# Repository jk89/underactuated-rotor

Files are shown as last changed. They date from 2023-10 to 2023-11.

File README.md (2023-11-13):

# Underactuatuated Rotor

Project for controlling a bldc motor with a ps4 controller, fulfilling the underactuated rotor mechanism.

# How to run

0. Load underactuated-arduino-uno.io onto device.
1. Start sending commands from ps4 controller to remote: python3 remoteCommand.py
2. Start graphing: bokeh serve --show graphServer.py 
3. Starting the Arduino Uno command server python3 commandServer.py

# [Circuit](https://github.com/kaepek/sbldc-smt)

# Models

## Minimal v1

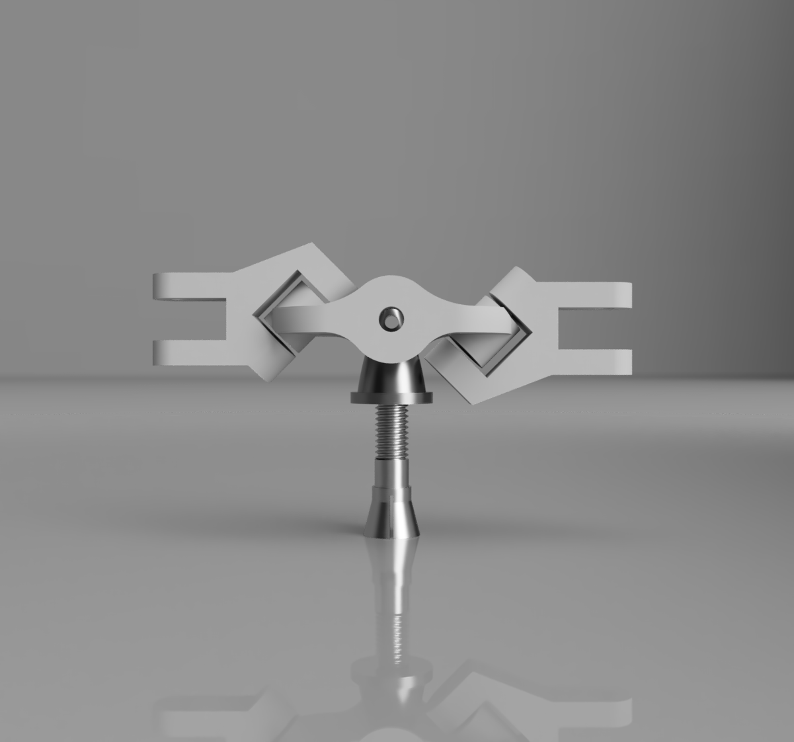
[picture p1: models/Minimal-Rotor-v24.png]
V1 model image

- [V1 model link](./models/Minimal-Rotor-v24.f3z)

## Hex Design v2

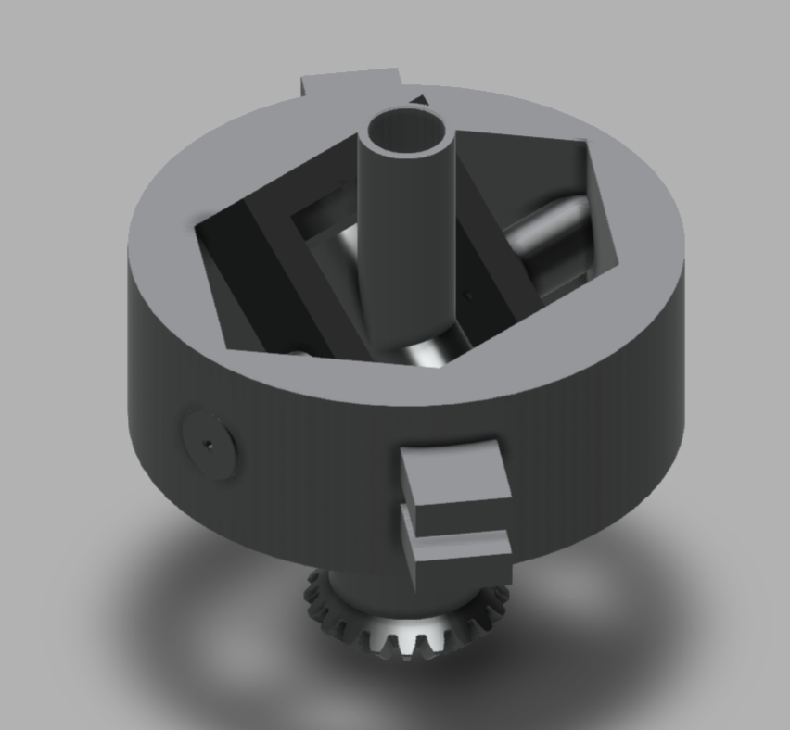
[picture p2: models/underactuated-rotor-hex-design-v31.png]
V2 model image

- [V2 model link](./models/underactuated-rotor-hex-design-v31.f3d)

## Hex Design v3

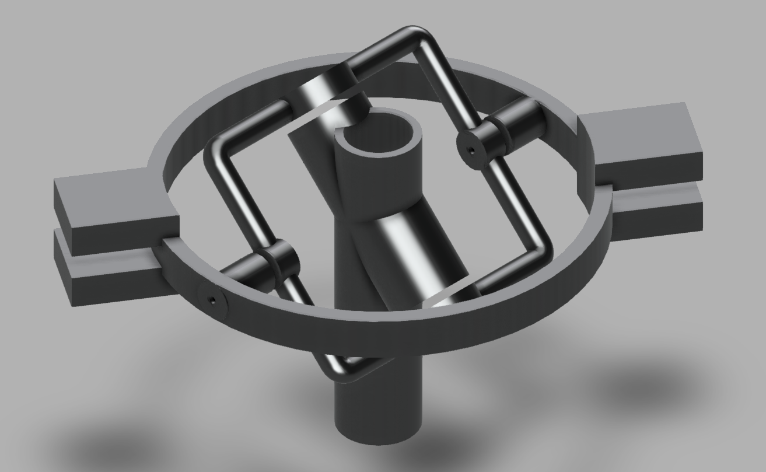
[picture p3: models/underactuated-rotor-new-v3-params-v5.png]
V3 model image

- [V3 model link](./models/underactuated-rotor-new-v3-params-v5.f3d)

# Draft notes on models:

[Notes](./resources/notes.pdf)

# Credits

- [Modlab UPenn](https://www.modlabupenn.org/underactuated-rotor/)
- [Paper](https://www.modlabupenn.org/wp-content/uploads/paulos_an_underactuated_propeller_IROS_2013.pdf)
- Steve Kelsey (Minimal rotor design)
- [Circuit reference](https://simple-circuit.com/arduino-sensorless-bldc-motor-controller-esc/)

# Disclaimer

This is an experimental project. I have destroyed a great deal of hardware (motors, transistors, ICs) and almost caused a fire once. Please be careful when using this code. ABSOLUTELY NO WARRANTY. If you do not agree to this then please do not download this software as this would violate the license which this code was distributed with, see [./LICENSE](./LICENSE) for details.

Moreover this project lacks sensible precautions with the ESC to halt the motor when its in a faulty state (aka something is in the way of the motor spinning). Due to its prototype nature represents a threat to you, if suitable personal protective gear and precautions are not made. I recommend building some sort of protective enclosure before one could safely experiment with the setup.

# License

Work is licensed under a
Creative Commons Attribution-NonCommercial 4.0 International License.

You should have received a copy of the license along with this
work. If not, see <https://creativecommons.org/licenses/by-nc/4.0/> or [plain text license](https://creativecommons.org/licenses/by-nc/4.0/legalcode.txt)

Released under fair use for educational purposes, strictly not for commercial use.

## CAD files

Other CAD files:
models/Minimal-Rotor-v24.f3z
models/underactuated-rotor-hex-design-v31.f3d
models/underactuated-rotor-new-v3-params-v5.f3d

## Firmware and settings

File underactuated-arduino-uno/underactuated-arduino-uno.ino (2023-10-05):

#define PWM_MAX_DUTY 240
#define PWM_MIN_DUTY 20
#define PWM_START_DUTY 20
#define n_BLDC_cycles 7
#define PI 3.1415926535897932384626433832795
#define MAX_PITCHROLL 32767

const float full_cycle = 2 * PI;
const byte motor_step_mod = n_BLDC_cycles * 6;
const float step_angle = full_cycle / motor_step_mod;

boolean modulated_thrust_mode = false;
const int EN1 = 2;
int x = 0;
byte bldc_step = 0, motor_speed;
int motor_step = 0;
int i = 0;

float sin_comp[motor_step_mod];
float cos_comp[motor_step_mod];
void build_angle_tables()
{
  for (byte z = 0; z < motor_step_mod; z++)
  {
    const float angle = step_angle * (float)z;
    sin_comp[z] = sin(angle);
    cos_comp[z] = cos(angle);
  }
}

float n_pitch = 0.0;
float n_roll = 0.0;
byte n_duty_target = PWM_START_DUTY;
byte duty_dynamic = n_duty_target;

/*
  port B digital pin x,x,13,12,11,10,9,8
  DDRB - The Port B Data Direction Register - read/write
  PORTB - The Port B Data Register - read/write
  PINB - The Port B Input Pins Register - read only
*/

/*
  portD digital pins 7,6,5,4,3,2,1,0
  DDRD - The Port D Data Direction Register - read/write
  PORTD - The Port D Data Register - read/write
  PIND - The Port D Input Pins Register - read only
*/

boolean first = true;

const int size_of_float = sizeof(float);
struct DATA_W
{
  float roll;
  float pitch;
} axesStuct;

void read_host_profile()
{
  char thrust = Serial.read();
  Serial.readBytes((char *)&axesStuct.roll, size_of_float);
  Serial.readBytes((char *)&axesStuct.pitch, size_of_float);
  n_pitch = axesStuct.pitch;
  n_roll = axesStuct.roll;
  n_duty_target = thrust;
}

void setup()
{

  build_angle_tables();
  modulated_thrust_mode = false;
  pinMode(EN1, OUTPUT);
  digitalWrite(EN1, HIGH);
  Serial.begin(9600);

  // portD digital pins 7,6,5,4,3,2,1,0
  // port B digital pin x,x,13,12,11,10,9,8

  DDRD |= B00111000; // 0x38;           // Configure pins 3, 4 and 5 as outputs
  PORTD = B00000000; // write all zeros to enable phase pins 3, 4, 5

  DDRB |= B00001110; // 0x0E;           // Configure pins 9, 10 and 11 as outputs
  PORTB = B00110001; // write zeros to 9, 10 , 11

  // Timer1 module setting: set clock source to clkI/O / 1 (no prescaling)
  TCCR1A = 0;
  TCCR1B = 0x01;
  // Timer2 module setting: set clock source to clkI/O / 1 (no prescaling)
  TCCR2A = 0;
  TCCR2B = 0x01;

  n_duty_target = PWM_START_DUTY;
  SET_PWM_DUTY(PWM_START_DUTY); // Setup starting PWM with duty cycle = PWM_START_DUTY

  // Analog comparator setting
  ACSR = 0x10; // Disable and clear (flag bit) analog comparator interrupt

  x = 0;
}

void loop()
{

  while (Serial.available() < 8)
  {
    delay(100);
  }
  read_host_profile();
  while (x < 1)
  {
    i = 5000;

    // Motor start
    while (i > 100)
    {
      delayMicroseconds(i);
      bldc_move();
      bldc_step++;
      bldc_step %= 6;
      motor_step++;
      motor_step %= motor_step_mod;
      i = i - 20;
    }
    x++;
  }

  motor_speed = PWM_START_DUTY;
  ACSR |= 0x08; // Enable analog comparator interrupt

  ADCSRA = (0 << ADEN); // Disable the ADC module
}

ISR(ANALOG_COMP_vect)
{
  // BEMF debounce
  for (i = 0; i < 10; i++)
  {
    if (bldc_step & 1)
    {
      if (!(ACSR & 0x20))
        i -= 1;
    }
    else
    {
      if ((ACSR & 0x20))
        i -= 1;
    }
  }

  bldc_move();
  bldc_step++;
  bldc_step %= 6;
  motor_step++;
  motor_step %= motor_step_mod;
  if (Serial.available() > 8)
  {
    read_host_profile();
    if (n_duty_target < 20)
    {
      setup();
      return;
    }
    else
    {
      modulated_thrust_mode = true;
    }
  }
  else if (modulated_thrust_mode == true)
  {
    // difference between max duty and target
    byte duty_available = min(PWM_MAX_DUTY - n_duty_target, n_duty_target);

    float sin_component = sin_comp[motor_step];
    float cos_component = cos_comp[motor_step];
    // roll sine
    float sin_comp = n_roll * duty_available * sin_component;
    // pitch cos
    float cos_comp = n_pitch * duty_available * cos_component;

    // thrust
    float thrust = round(sin_comp + cos_comp + n_duty_target);
    SET_PWM_DUTY_STALL((int)thrust);
  }
}

void bldc_move()
{ // BLDC motor commutation function
  switch (bldc_step)
  {
  case 0:
    AH_BL();
    BEMF_C_RISING();
    break;
  case 1:
    AH_CL();
    BEMF_B_FALLING();
    break;
  case 2:
    BH_CL();
    BEMF_A_RISING();
    break;
  case 3:
    BH_AL();
    BEMF_C_FALLING();
    break;
  case 4:
    CH_AL();
    BEMF_B_RISING();
    break;
  case 5:
    CH_BL();
    BEMF_A_FALLING();
    break;
  }
}

void BEMF_A_RISING()
{
  ADCSRA = (0 << ADEN); // Disable the ADC module
  ADCSRB = (1 << ACME);
  ADMUX = 1; // Select analog channel 1 as comparator negative input
  ACSR |= 0x03;
}
void BEMF_A_FALLING()
{
  ADCSRA = (0 << ADEN); // Disable the ADC module
  ADCSRB = (1 << ACME);
  ADMUX = 1; // Select analog channel 1 as comparator negative input
  ACSR &= ~0x01;
}

void BEMF_B_RISING()
{
  ADCSRA = (0 << ADEN); // Disable the ADC module
  ADCSRB = (1 << ACME);
  ADMUX = 2; // Select analog channel 2 as comparator negative input
  ACSR |= 0x03;
}
void BEMF_B_FALLING()
{
  ADCSRA = (0 << ADEN); // Disable the ADC module
  ADCSRB = (1 << ACME);
  ADMUX = 2; // Select analog channel 2 as comparator negative input
  ACSR &= ~0x01;
}

void BEMF_C_RISING()
{
  ADCSRA = (0 << ADEN); // Disable the ADC module
  ADCSRB = (1 << ACME);
  ADMUX = 3; // Select analog channel 3 as comparator negative input
  ACSR |= 0x03;
}
void BEMF_C_FALLING()
{
  ADCSRA = (0 << ADEN); // Disable the ADC module
  ADCSRB = (1 << ACME);
  ADMUX = 3; // Select analog channel 3 as comparator negative input
  ACSR &= ~0x01;
}

void AH_BL()
{
  PORTB = 0x04;
  PORTD &= ~0x18;
  PORTD |= 0x20;
  TCCR1A = 0;    // Turn pin 11 (OC2A) PWM ON (pin 9 & pin 10 OFF)
  TCCR2A = 0x81; //
}
void AH_CL()
{
  PORTB = 0x02;
  PORTD &= ~0x18;
  PORTD |= 0x20;
  TCCR1A = 0;    // Turn pin 11 (OC2A) PWM ON (pin 9 & pin 10 OFF)
  TCCR2A = 0x81; //
}
void BH_CL()
{
  PORTB = 0x02;
  PORTD &= ~0x28;
  PORTD |= 0x10;
  TCCR2A = 0;    // Turn pin 10 (OC1B) PWM ON (pin 9 & pin 11 OFF)
  TCCR1A = 0x21; //
}
void BH_AL()
{
  PORTB = 0x08;
  PORTD &= ~0x28;
  PORTD |= 0x10;
  TCCR2A = 0;    // Turn pin 10 (OC1B) PWM ON (pin 9 & pin 11 OFF)
  TCCR1A = 0x21; //
}
void CH_AL()
{
  PORTB = 0x08;
  PORTD &= ~0x30;
  PORTD |= 0x08;
  TCCR2A = 0;    // Turn pin 9 (OC1A) PWM ON (pin 10 & pin 11 OFF)
  TCCR1A = 0x81; //
}
void CH_BL()
{
  PORTB = 0x04;
  PORTD &= ~0x30;
  PORTD |= 0x08;
  TCCR2A = 0;    // Turn pin 9 (OC1A) PWM ON (pin 10 & pin 11 OFF)
  TCCR1A = 0x81; //
}

int SET_PWM_DUTY(byte duty)
{
  if (duty < PWM_MIN_DUTY)
    duty = PWM_MIN_DUTY;
  if (duty > PWM_MAX_DUTY)
    duty = PWM_MAX_DUTY;
  OCR1A = duty; // Set pin 9  PWM duty cycle
  OCR1B = duty; // Set pin 10 PWM duty cycle
  OCR2A = duty; // Set pin 11 PWM duty cycle
  return duty;
}

int SET_PWM_DUTY_STALL(byte duty)
{
  OCR1A = duty; // Set pin 9  PWM duty cycle
  OCR1B = duty; // Set pin 10 PWM duty cycle
  OCR2A = duty; // Set pin 11 PWM duty cycle
  return duty;
}

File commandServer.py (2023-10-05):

import socket
import json
import struct
import math
import serial

# i listen on port 5000 and send commands to the ard
myIp = "127.0.0.1"
myPort = 5000
sock = socket.socket(socket.AF_INET, socket.SOCK_DGRAM) 
sock.bind((myIp, myPort))
# open serial port
ser = serial.Serial('/dev/ttyACM0') 

#{'ljx': -6419}}, {'ljy': 0, 'ljx': -6419, 'rt': 207})
#({'type': 'axes', 'value': {'ljx': -6081}}, {'ljy': 0, 'ljx': -6081, 'rt': 207})
#({'type': 'axes', 'value': {'ljx': -6419}}, {'ljy': 0, 'ljx': -6419, 'rt': 207})
#({'type': 'axes', 'value': {'ljx': -6081}}, {'ljy': 0, 'ljx': -6081, 'rt': 207})
#({'type': 'axes', 'value': {'ljx': -6419}}, {'ljy': 0, 'ljx': -6419, 'rt': 207})
#({'type': 'axes', 'value': {'ljx': -6081}}, {'ljy': 0, 'ljx': -6081, 'rt': 207})
#({'type': 'axes', 'value': {'ljx': -6419}}, {'ljy': 0, 'ljx': -6419, 'rt': 207})
#({'type': 'axes', 'value': {'ljx': -6081}}, {'ljy': 0, 'ljx': -6081, 'rt': 207})
#({'type': 'axes', 'value': {'ljx': -6419}}, {'ljy': 0, 'ljx': -6419, 'rt': 207})
#({'type': 'axes', 'value': {'ljx': -6081}}, {'ljy': 0, 'ljx': -6081, 'rt': 207})
#({'type': 'axes', 'value': {'ljx': -6419}}, {'ljy': 0, 'ljx': -6419, 'rt': 207})
#({'type': 'axes', 'value': {'ljx': -6081}}, {'ljy': 0, 'ljx': -6081, 'rt': 207})
#({'type': 'axes', 'value': {'ljx': -6419}}, {'ljy': 0, 'ljx': -6419, 'rt': 207})
#({'type': 'axes', 'value': {'ljx': -6081}}, {'ljy': 0, 'ljx': -6081, 'rt': 207})
#({'type': 'axes', 'value': {'ljx': -6419}}, {'ljy': 0, 'ljx': -6419, 'rt': 207})
#({'type': 'axes', 'value': {'ljx': -6081}}, {'ljy': 0, 'ljx': -6081, 'rt': 207})

def printNByte(target, n):
    return ((target&(0xFF<<(8*n)))>>(8*n)) # hex

axisMaxValue = 32767
def normaliseProfile(roll, pitch, thrust):
    global axisMaxValue
    # normalise between -1 to 1 on
    normRoll = roll / axisMaxValue
    normPitch = pitch / axisMaxValue
    # project inside a unit circle using elipse formula
    normRollAuthorityAdjusted = normRoll * math.sqrt(1 - ((normPitch * normPitch)/2)) 
    normPitchAuthorityAdjusted = normPitch * math.sqrt(1 - ((normRoll * normRoll)/2))
    return (normRollAuthorityAdjusted, normPitchAuthorityAdjusted, thrust)

def createArdByteString(roll, pitch, thrust):
    binaryString = bytes([thrust])
    binaryString = binaryString + struct.pack("<ff", roll, pitch)
    return binaryString 

nullProfile = createArdByteString(0, 0, 0)
def performStateChange(stateChange):
    if stateChange["type"] == "axes":
        value = stateChange["value"]
        #create binary profile
        (roll, pitch, thrust) = normaliseProfile(value["ljx"], value["ljy"], value["rt"])
        profile = createArdByteString(pitch, roll, thrust)
        if thrust == 0:
            return
        if thrust < 20:
            profile = createArdByteString(roll, pitch, 20)
        ser.write(profile)
        print(("profile", profile, len(profile)))
    else:
        if stateChange["value"] == "x":
            ser.write(nullProfile)
            print(("profile", nullProfile))
        elif stateChange["value"] == "t":
            startProfile = createArdByteString(0, 0, 20)
            ser.write(startProfile)
            print(("profile", startProfile))
    print(stateChange)

while True:
    data, addr = sock.recvfrom(1024) # buffer size is 1024 bytes
    jsonProfile = json.loads(data)
    performStateChange(jsonProfile)
